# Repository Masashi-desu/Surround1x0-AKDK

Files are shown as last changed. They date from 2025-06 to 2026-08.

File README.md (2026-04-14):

# Surround1x0-AKDK

Generated by [Auto-Keyboard-Design-Kit](https://auto-kdk.pages.dev/)

## Preview

- 3D View

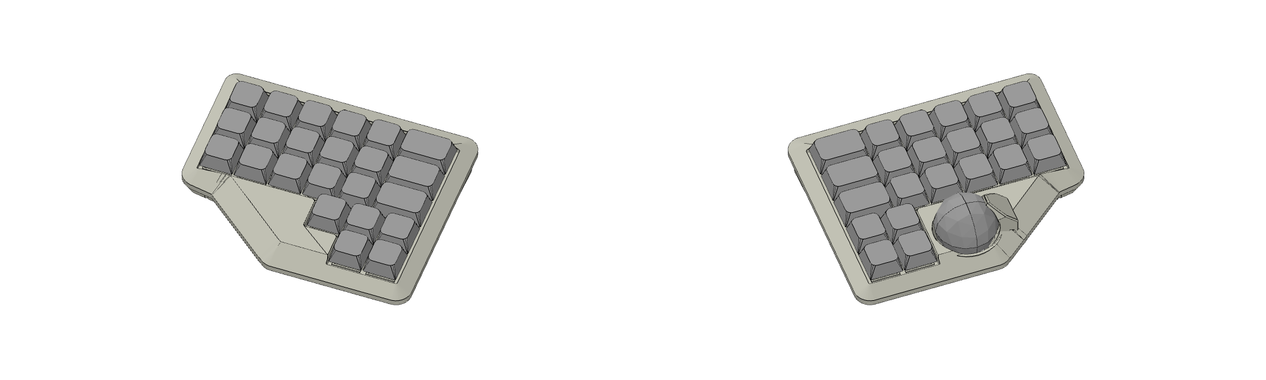
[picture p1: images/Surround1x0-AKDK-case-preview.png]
Case Preview


- Top View

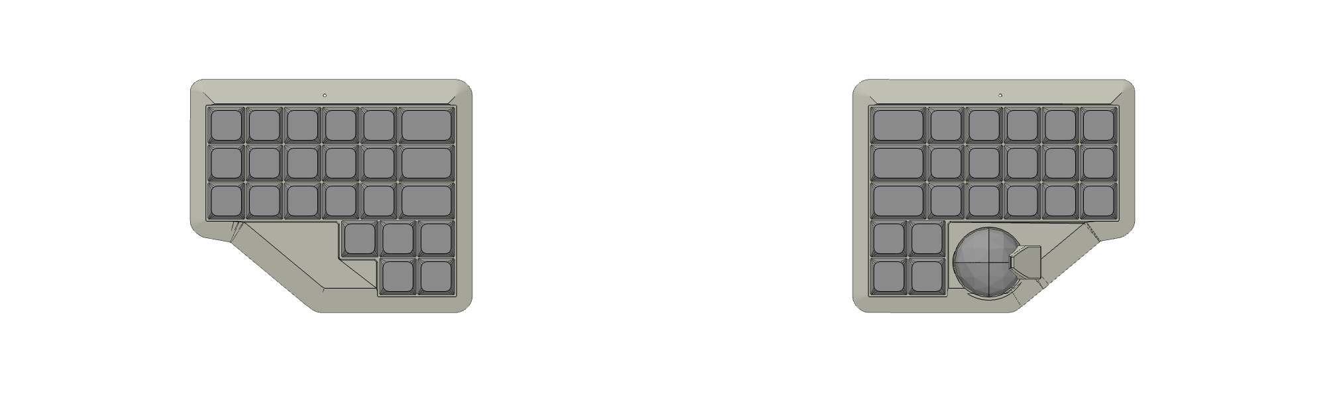
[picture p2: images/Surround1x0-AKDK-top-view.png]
Top View


## Keymap

Mac/Win と US/JIS の差分キーは、それぞれ `Mac/Win` と `US/JIS` の順で表記しています。SVG は `config/keymap.keymap` から自動生成されます。

Keymap

## Parts List

|Part|Quantity|
|---|---|
|wireless controller|2|
|Conthrough(2.5mm, 9pin)|4|
|Battery|2|
USB-C cable|1|
|Choc V2 switch and socket|45|
|Diode|45|
|Keycap|45|

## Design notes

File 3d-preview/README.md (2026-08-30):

# 3D preview model pipeline

`3d-preview` は、Blender の編集元データ、リポジトリ内の設計データから部品を再生成するスクリプト、検証用スクリプト、Web 向け GLB の書き出し処理をまとめたディレクトリです。

編集の中心は [`Surround1x0-AKDK.blend`](./Surround1x0-AKDK.blend) です。自動生成された部品を手作業で直すのではなく、原則として対応する入力データまたは `scripts/` 内の生成スクリプトを修正して再生成します。

## 全体の関係

```text
pcb/*.json ──────────────> build_pcb_from_repository.py ──> PCB
                                  │
                                  ├─> build_choc_hotswap_sockets.py
                                  ├─> build_controller_sensor_modules.py
                                  └─> setup_assembly_exploded_view.py

keycaps/ ────────────────> 利用者がカスタムできる3Dプリント用成果物

.blend 内のキーキャップ ─> build_choc_v2_switches.py ─────> Switches

生成済みの各部品 ─────────> verify_*.py / render_*.py ───────> .tmp/ の検証資料

更新済み .blend ─────────> setup_assembly_exploded_view.py ─> 分解レイヤー
        └────────────────> export_web_glb.py ───────────────> Black / White / Web GLB
```

基本の更新順は次のとおりです。

1. 変更対象に対応する生成スクリプトだけを実行する。PCB、ソケット、コントローラー／センサーをまとめて更新するときは `build_pcb_from_repository.py` を使う。
2. 対応する `verify_*.py` を実行する。
3. 個別の生成スクリプトを実行した場合や親子関係を変更した場合は、`setup_assembly_exploded_view.py` を再実行する。
4. Web用モデルを更新するときは、最後に `export_web_glb.py` で GLB を書き出す。

これは全工程を毎回実行するための固定ワークフローではありません。変更した部品に関係する処理だけを選んで使用します。

## 主要な生成・更新スクリプト

| スクリプト | 主な入力 | `.blend` への変更 | 保存と依存関係 |
| --- | --- | --- | --- |
| [`build_choc_v2_switches.py`](./scripts/build_choc_v2_switches.py) | `.blend` 内の既存スイッチ位置とキーキャップの `module_id` / `profile` | Kailh Choc V2 の各部品を再生成 | 単体では保存も分解レイヤー再構築もしない。実行後に保存し、続けて分解ビューを更新する |
| [`build_pcb_from_repository.py`](./scripts/build_pcb_from_repository.py) | `../pcb/Surround1x0-AKDK-{left,right}-pcb.json` | 左右 PCB の外形、穴、銅箔などを再生成 | ソケット生成、コントローラー／センサー生成、分解ビュー設定を内部で順番に呼び出し、最後に `.blend` を保存する |
| [`build_choc_hotswap_sockets.py`](./scripts/build_choc_hotswap_sockets.py) | PCB JSON 内の CPG135001S30 フットプリント | ホットスワップソケットを再生成 | 単独実行時も分解ビューを更新して `.blend` を保存する。PCB 一括生成からも呼ばれる |
| [`build_controller_sensor_modules.py`](./scripts/build_controller_sensor_modules.py) | PCB の配置情報、Auto-KDK とマウスセンサーの寸法・参照情報 | コントローラー、コンスルー、電池／コネクター、マウスセンサー、FPC を再生成 | 既定では分解ビューを更新して `.blend` を保存する。PCB 一括生成からも呼ばれる。`--no-save` と `--no-exploded` を指定可能 |
| [`setup_assembly_exploded_view.py`](./scripts/setup_assembly_exploded_view.py) | 現在の Blender オブジェクトとカスタムプロパティ | 部品を分解レイヤー用 Empty に再分類し、ドライバーを設定 | `.blend` を保存する。`--spacing`、`--assembled`、`--output` を指定可能 |
| [`export_web_glb.py`](./scripts/export_web_glb.py) | 更新済みの `.blend` とマテリアル | 書き出し時だけ組立状態と色を適用 | `.blend` は保存せず、3 個の GLB を出力する。キー刻印の `Legend_*` は出力対象外 |

### PCB 一括生成について

`build_pcb_from_repository.py` は PCB だけのスクリプト名ですが、内部で次も再生成します。

```text
build_pcb_from_repository.py
├── build_choc_hotswap_sockets.py
├── build_controller_sensor_modules.py
└── setup_assembly_exploded_view.py
```

したがって通常の構成同期では `npm run model:pcb` を 1 回実行すれば、PCB、ソケット、コントローラー／センサー、分解レイヤーまで更新されます。ソケットまたはコントローラーだけを調整しているときは、対応する個別コマンドを使えます。

## キーキャップ成果物とBlenderモデル

[`../keycaps`](../keycaps) は、利用者がそのまま3Dプリントしたり、用途に合わせてカスタムしたりできる配布成果物です。Blenderモデルの自動生成依存ではなく、独立した成果物としてバージョン管理します。このため、配布元や生成時のファイル名が変わっても `3d-preview` のスクリプト変更は必要ありません。

現在の [`Surround1x0-AKDK.blend`](./Surround1x0-AKDK.blend) には、今回取り込んだキーキャップ形状が格納済みです。`keycaps/` からBlenderへ再取り込みする常設スクリプトは置かず、将来モデル側も更新するときは、その時点の形状と要件に合わせて作業します。3MFは黒色キーボード向けですが、Blender上の色はマテリアルと `export_web_glb.py` のカラーバリエーションが管理します。

- ハイプロファイルのホーミングは、大西配列の T と O に相当する左右の物理位置 `switch-01-03` に割り当てる。
- ロープロファイルのホーミングは、手前側の外端、つまり左手 DEF と右手 BSP に割り当てる。
- 白黒ともキー刻印は表示しない。Blender 内の `Legend_*` も非表示にし、GLB 書き出し時にも除外する。
- 白ではハイプロファイルのホーミングバーとトラックボールにグレーを使う。
- Web ビューアー上での動的な色切り替えは [`../site/src/main.js`](../site/src/main.js)、書き出し済み Black / White GLB の色は [`export_web_glb.py`](./scripts/export_web_glb.py) が管理する。

## 検証スクリプト

検証スクリプトは `.blend` を更新せず、リポジトリ直下の `.tmp/` に JSON や SVG を生成します。

| 生成対象 | 検証スクリプト | 主な出力先 |
| --- | --- | --- |
| PCB | [`verify_pcb_holes.py`](./scripts/verify_pcb_holes.py) | `../.tmp/pcb-hole-verification/` |
| ホットスワップソケット | [`verify_choc_hotswap_sockets.py`](./scripts/verify_choc_hotswap_sockets.py) | `../.tmp/socket-model/` |
| コントローラー／センサー | [`verify_controller_sensor_modules.py`](./scripts/verify_controller_sensor_modules.py) | `../.tmp/controller-sensor-model/` |

形状生成スクリプトを変更した場合は、最低でも対応する検証スクリプトを再実行します。`build_pcb_from_repository.py` は複数部品を更新するため、PCB、ソケット、コントローラー／センサーの 3 検証を実行します。

## レンダリングとオーバーレイ

次のスクリプト群は、寸法検証を画像で確認するための補助処理です。`render_*.py` は Blender で現在モデルをレンダリングし、対応する `make_*.py` は Pillow を使って参照画像や測定値との比較画像を作ります。

| 対象 | Blender レンダリング | オーバーレイ生成 | 出力先 |
| --- | --- | --- | --- |
| コントローラー／センサー | [`render_controller_sensor_validation.py`](./scripts/render_controller_sensor_validation.py) | [`make_controller_sensor_overlays.py`](./scripts/make_controller_sensor_overlays.py) | `../.tmp/controller-sensor-model/` |
| コントローラーとケース | [`render_controller_case_alignment.py`](./scripts/render_controller_case_alignment.py) | [`make_controller_case_overlays.py`](./scripts/make_controller_case_overlays.py) | `../.tmp/controller-bottom-reference/output/` |
| マウスセンサーとケース | [`render_mouse_sensor_alignment.py`](./scripts/render_mouse_sensor_alignment.py) | [`make_mouse_sensor_alignment_overlays.py`](./scripts/make_mouse_sensor_alignment_overlays.py) | `../.tmp/mouse-sensor-alignment/` |

オーバーレイ生成は、対応するレンダリングと必要な `verify_*.py` の測定 JSON を先に作ってから実行します。`.tmp/` 以下は再生成可能な検証成果物で、編集元データではありません。

## 実行方法

### npm コマンド

Blender の主要コマンドは [`../site/package.json`](../site/package.json) に定義されています。`site` ディレクトリから実行します。

```sh
cd site

npm run model:pcb
npm run model:verify:pcb
npm run model:verify:socket
npm run model:verify:controller
npm run model:export
```

個別更新用に `npm run model:socket` と `npm run model:controller` もあります。`npm run model:sync` は `model:pcb` の後に `model:export` を実行しますが、検証は含みません。

### Blender スクリプトの直接実行

`package.json` にないスクリプトは、リポジトリ直下から次の形式で実行できます。

```sh
BLENDER=/Applications/Blender.app/Contents/MacOS/Blender

"$BLENDER" \
  --background 3d-preview/Surround1x0-AKDK.blend \
  --python-exit-code 1 \
  --python 3d-preview/scripts/verify_pcb_holes.py
```

引数を受け取るスクリプトでは、Blender の引数との境界に `--` を置きます。

```sh
"$BLENDER" \
  --background 3d-preview/Surround1x0-AKDK.blend \
  --python-exit-code 1 \
  --python 3d-preview/scripts/setup_assembly_exploded_view.py \
  -- --spacing 30
```

`build_choc_v2_switches.py` は単体では `.blend` を保存しないため、Blender の Scripting ワークスペースで実行して結果を確認し、明示的に保存してください。

## GLB の出力先

`export_web_glb.py` は、分解ビューのドライバーを一時的に組立状態へそろえ、次を出力します。

| 出力 | 用途 |
| --- | --- |
| [`Surround1x0-AKDK-Black.glb`](./Surround1x0-AKDK-Black.glb) | 黒カラーバリエーションの確認用 |
| [`Surround1x0-AKDK-White.glb`](./Surround1x0-AKDK-White.glb) | 白カラーバリエーションの確認用 |
| [`../site/public/models/surround1x0-akdk.glb`](../site/public/models/surround1x0-akdk.glb) | Web ビューアーが読み込む配信用モデル |

書き出し後は `site` で `npm run build` を実行し、Web 側のモデル読み込みと色切り替えを確認します。

## 更新時のチェックリスト

- 生成物ではなく、対応する設計データまたは生成スクリプトを修正したか。
- 変更した部品に対応する `verify_*.py` を実行したか。
- 新しいオブジェクトを追加した場合、分解レイヤーを再構築したか。
- Black / White / Web の 3 GLB を再出力したか。
- Web 側の色定義も変更した場合、`site/src/main.js` と `export_web_glb.py` の役割の違いを確認したか。

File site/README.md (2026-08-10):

# Surround1x0-AKDK Three.js Preview

ViteとThree.jsで`3d-preview/Surround1x0-AKDK.blend`のGLBを表示します。

```bash
cd site
npm install
npm run model:sync
npm run dev
```

## 機能

- Black / Warm Ivory / GLB Originalの色表示切替
- 全体、左手側、右手側、PCB基板、Auto-KDKマイコン基板、コンスルーピン、マウスセンサー、ケース、スイッチ、スイッチソケット、キーキャップ、トラックボール、コネクタ表示
- Choc V2茶軸／青軸を内部部品ではなく一式として選べる代表単体表示
- キースイッチ単体表示中の内部パーツExploded View
- ケース上下、ソケット、PCB、コンスルー、マイコン基板、マウスセンサー、スイッチ、キーキャップ、トラックボールのExploded View
- 分解量スライダー、表示対象へのカメラフィット、視点リセット

GLBはBlenderの`exploded_view_layer`と`exploded_view_order`カスタムプロパティを
保持します。スイッチ内部の部品はGLBに含まれますが、WebのExploded Viewでは
スイッチ一式として動きます。表示対象から個別のキースイッチを選択した場合だけ、
「分解」でケース・ステム・ばね・接点などの内部パーツを展開します。

## PCBからプレビューへの反映

`pcb/Surround1x0-AKDK-left-pcb.json`と
`pcb/Surround1x0-AKDK-right-pcb.json`を元に、基板外形、配線、露出パッド、
シルクと実際に貫通したドリル穴を持つベアPCBをBlenderへ再生成します。
EasyEDAの`HOLE`と多層`PAD`のドリル値は半径として読み取り、直径へ変換してBoolean加工します。
マイコン接続用フットプリントのスルーホールとパッドはPCB側に残し、Auto-KDK基板、
9ピン×2列のコンスルー、LiPoはそれぞれ独立ジオメトリとして配置します。
右手側には13.4 × 7.4 mmのPAW3222マウスセンサー基板と0.5 mmピッチ6ピンFPCも配置します。
スイッチソケットはCPG135001S30のデータシート寸法とEasyEDAの実穴位置を元に、
PCBとは別の独立パーツとして45個配置します。ダイオードは引き続きPCBモデルには
含めず、独立パーツとして追加できる構成です。

```bash
cd site
npm run model:sync
```

`model:sync`はBlenderファイルを更新してから、サイト用GLBを再出力します。

穴加工をEasyEDAの元データと照合する場合は、次を実行します。

```bash
npm run model:verify:pcb
npm run model:verify:socket
npm run model:verify:controller
```

検証結果は`.tmp/pcb-hole-verification/`へ出力され、参照穴と生成メッシュの
全体／拡大オーバーレイ、および中心・直径誤差のJSONを確認できます。
ソケットの寸法・ボス径・PCB穴中心との位置合わせは`.tmp/socket-model/`へ
オーバーレイと測定JSONを出力します。
Auto-KDK基板、コンスルーピン、マウスセンサー、FPCの寸法・配置検証は
`.tmp/controller-sensor-model/`へ測定JSON、レンダー、参照写真オーバーレイを出力します。

## GitHub Pagesへのデプロイ

`main`ブランチへのpushで`site/**`に変更が含まれる場合、
`.github/workflows/deploy-site-pages.yml`がViteをビルドしてGitHub Pagesへデプロイします。
Actionsタブから手動実行することもできます。

初回のみ、GitHubの「Settings → Pages → Build and deployment → Source」で
`GitHub Actions`を選択してください。PagesのベースパスはWorkflowからViteへ自動的に渡されます。

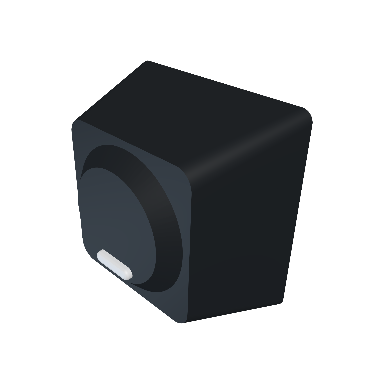
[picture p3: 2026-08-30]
keycaps/keycaps/Hiprofile-1u-Homing-519426ae.png

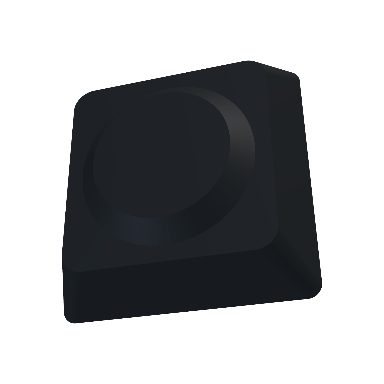
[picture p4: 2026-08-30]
keycaps/keycaps/Lowprofile-1u-93ce7806.png

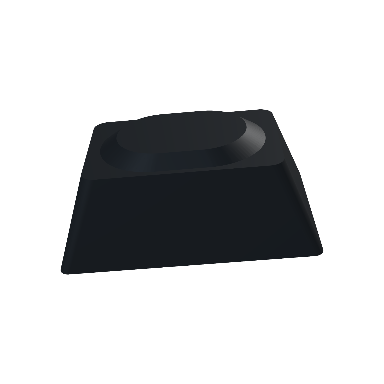
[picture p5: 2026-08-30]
keycaps/keycaps/Hiprofile-1.5u-16350801.png

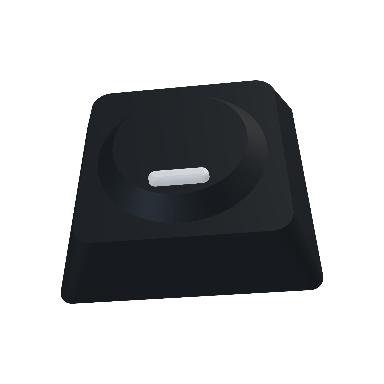
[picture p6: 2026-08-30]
keycaps/keycaps/Lowprofile-1u-Homing-1a3ae35f.png

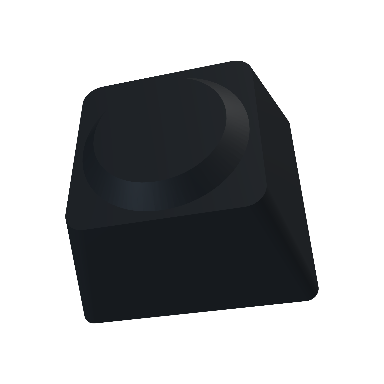
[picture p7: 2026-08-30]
keycaps/keycaps/Hiprofile-1u-170342f3.png

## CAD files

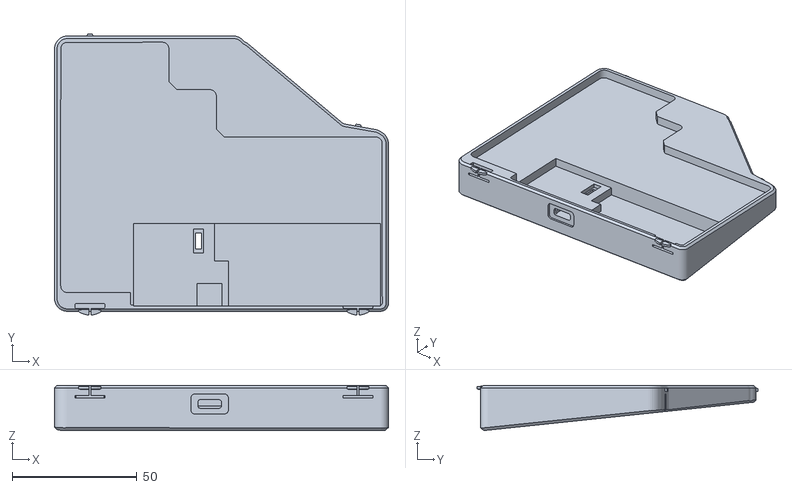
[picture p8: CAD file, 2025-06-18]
case/Surround1x0-AKDK-left-bottom-case.stl
133.9 x 112.7 x 18.1

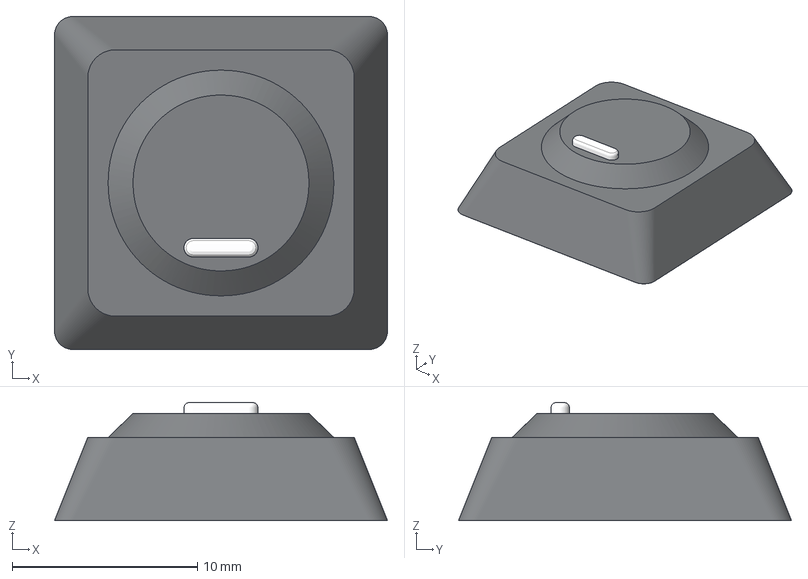
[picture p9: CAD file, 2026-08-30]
keycaps/3mf/Lowprofile-1u-Homing-1a3ae35f.3mf
18.0 x 18.0 x 6.41 mm

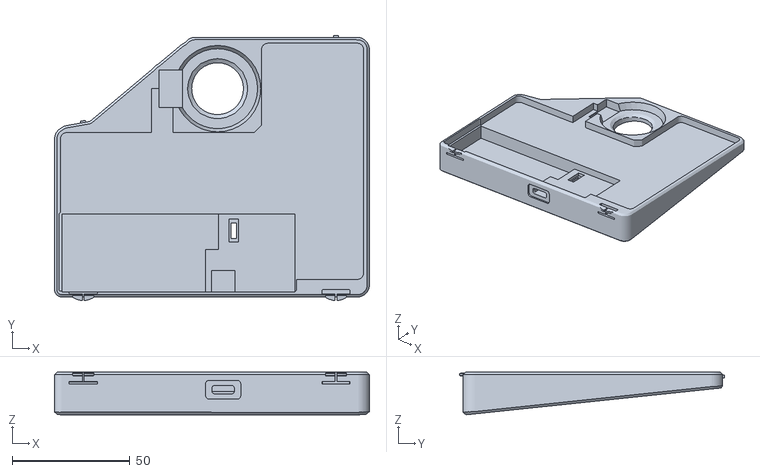
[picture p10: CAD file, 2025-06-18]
case/Surround1x0-AKDK-right-bottom-case.stl
133.9 x 112.6 x 18.1

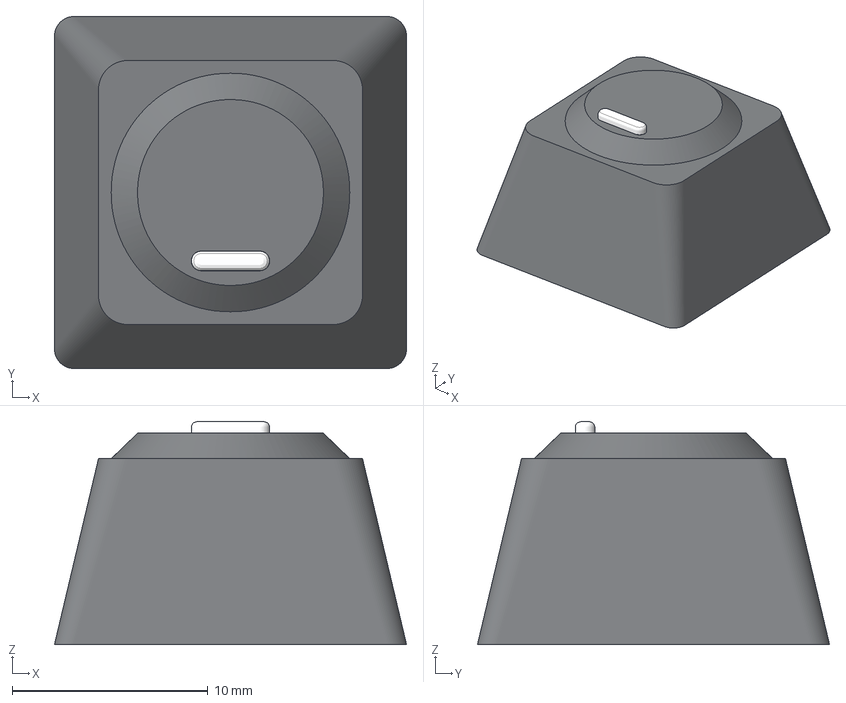
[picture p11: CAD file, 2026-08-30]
keycaps/3mf/Hiprofile-1u-Homing-519426ae.3mf
18.0 x 18.0 x 11.4 mm

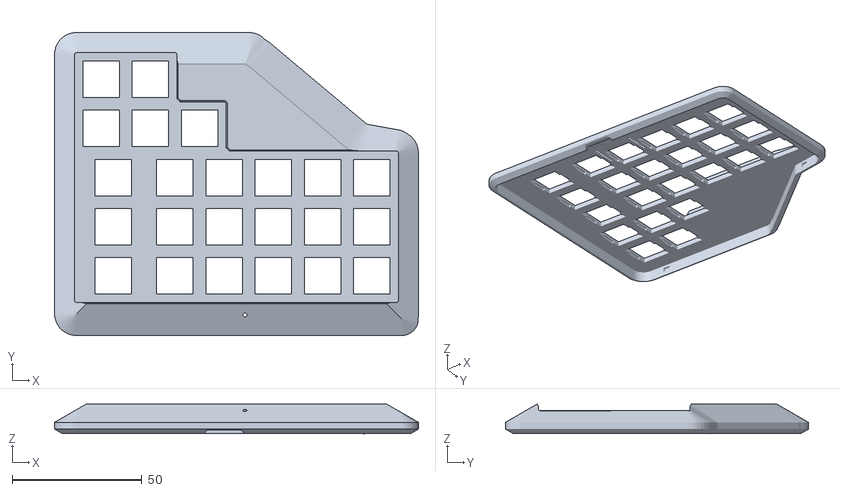
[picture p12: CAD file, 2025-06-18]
case/Surround1x0-AKDK-left-top-case.stl
140.5 x 117.0 x 11.4

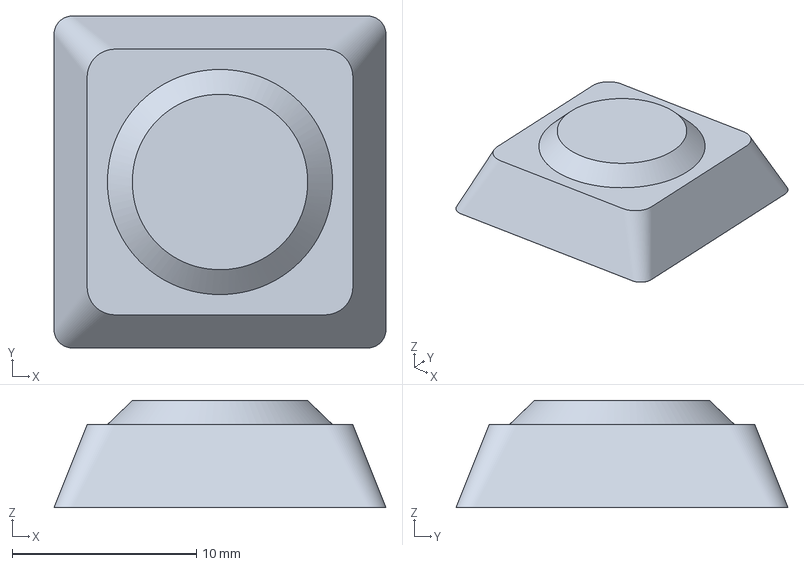
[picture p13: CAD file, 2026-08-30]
keycaps/3mf/Lowprofile-1u-93ce7806.3mf
18.0 x 18.0 x 5.81 mm

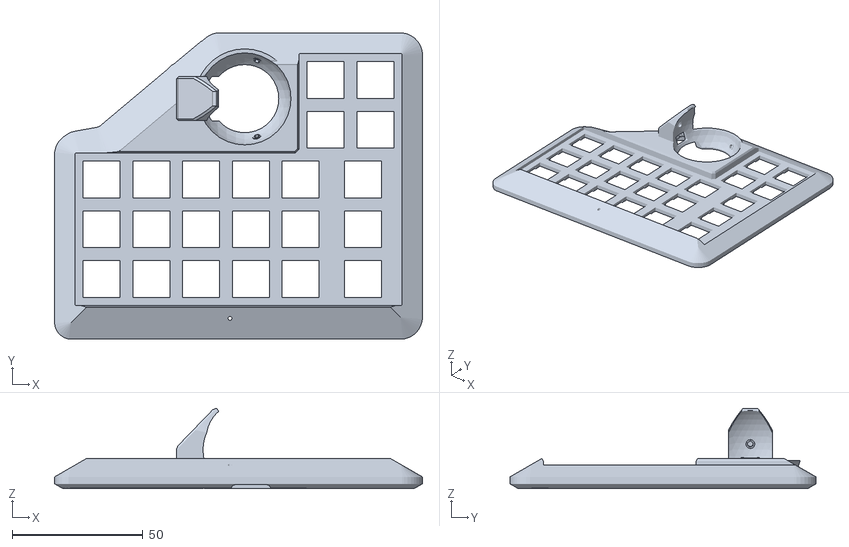
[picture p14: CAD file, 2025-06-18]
case/Surround1x0-AKDK-right-top-case.stl
140.5 x 117.0 x 30.6

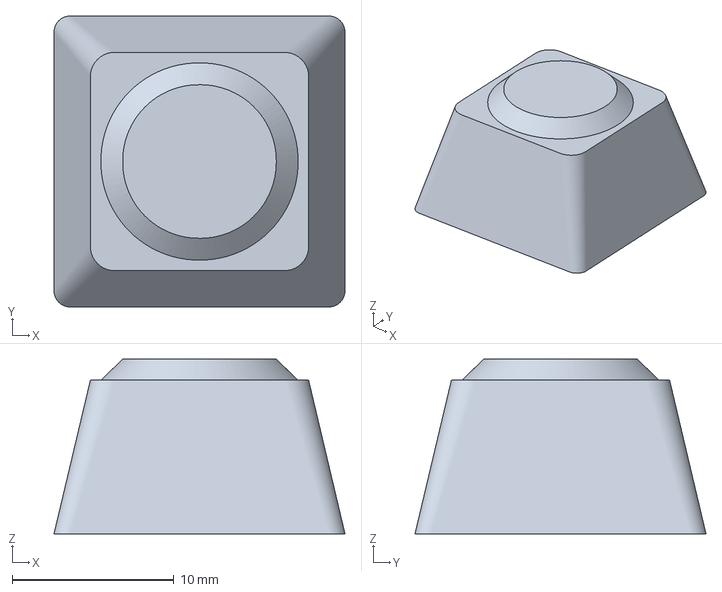
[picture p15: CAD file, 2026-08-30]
keycaps/3mf/Hiprofile-1u-170342f3.3mf
18.0 x 18.0 x 10.8 mm

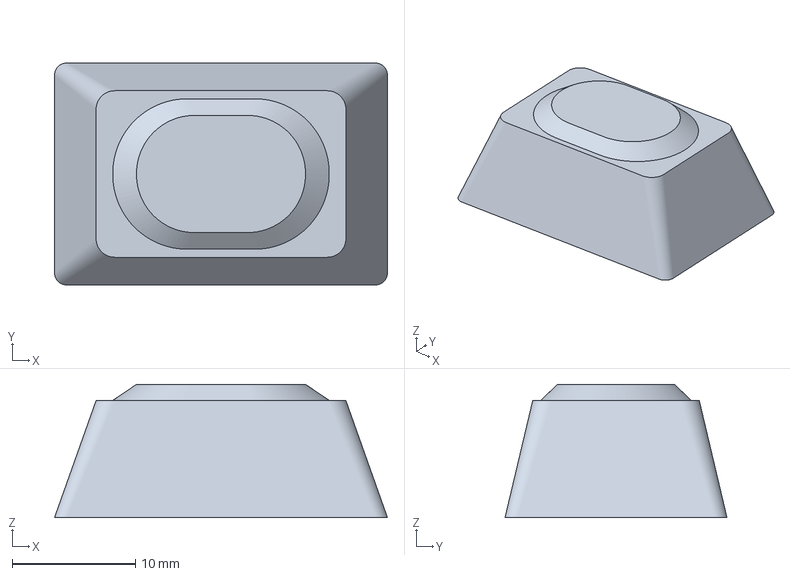
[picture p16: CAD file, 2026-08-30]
keycaps/3mf/Hiprofile-1.5u-16350801.3mf
27.0 x 18.0 x 10.8 mm

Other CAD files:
3d-preview/Surround1x0-AKDK.blend

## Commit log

2025-06-18 Update surround1x0_akdk_right.conf (#1)
    BUILD_ASSERT(DEVICE_NAME_LEN < CONFIG_BT_DEVICE_NAME_MAX);
    でエラーになる問題を修正。
2025-06-22 装飾、レイヤの改善
2025-06-28 コンボ追加。リファクタ
2025-06-28 レイヤをリセットするカスタムビヘイビアを追加
2025-06-28 binding-cells不足の問題を修正
2025-06-28 カスタムビヘイビアではなくto0を使用する方針へ変更
2025-06-28 大西配列に変更
2025-06-28 キーマップ調整
2025-06-28 コンボの発火時間を調整
2025-06-28 btレイヤ移動を変更
2025-06-29 キーマップ 微調整
2025-06-29 キーマップ微調整 MOVEレイヤから入力レイヤに戻れない問題を修正
2025-06-29 キーマップ微調整
2025-07-05 移動キー装飾キーの調整
2025-07-05 キーマップの調整
2025-07-05 移動用レイヤの改善
2025-07-06 プレビュー追加
2025-07-13 操作関連のキーマップを調整
2025-07-27 レイヤ移動とキーマップの改善
2025-07-27 キーマップ改善 Fnレイヤ移動
2025-07-30 数値、記号のレイヤの左側を移動レイヤと同じキーマップに変更
2025-07-30 レイヤの設定ミスを修正
2025-08-09 キーマップの改善
2025-08-11 トラックボールスクロール用のレイヤーを追加
2025-08-11 トラックボールスクロール対応
    トラックボールによるスクロールに対応する設定を追加
2025-08-11 自動スリープ機能の追加
    10分で自動スリープになるように設定を追加。
2025-08-11 デバッグ用のdump-configを追加
    “Dump final .config (right shield)” が走って、build-right/zephyr/.config を Artifacts: config-right としてダウンロードできるようになります。
2025-08-11 dump-config ジョブのコンテナを変更
2025-08-11 コンパイルせず.config を生成
2025-08-11 zephyr/.config ターゲットだけをビルドして .configを生成
2025-08-11 Revert "自動スリープ機能の追加"
    This reverts commit eed534183a3a0270cfe6c621140d1b21c4935140.
2025-08-11 スリープモード関係の変更を取り消し
2025-08-11 スリープモードの追加
    10分でスリープ状態に移行し、Centralのキーを押すことで復帰します。
    peripheralやトラックボールからのwakeは一旦対象外とします。
2025-08-11 トラックボールのスクロールを反転
    トラックボールのスクロールを変更することでスワイプのように操作できるように変更。
2025-08-11 ビルド時に短縮ハッシュをファイル名に付与
2025-08-11 409 Conflict 修正
    同名アーティファクトを上書き
2025-08-11 アーティファクト名に短縮ハッシュを付与
2025-08-11 ワークフローを簡略化
2025-08-11 一旦アーティファクトのリネームは保留
2025-08-11 スクロール反転
2025-08-11 修正 missing data after phandle
2025-08-11 scroller の input-processors を X反転 と Y反転 を 別々の zip_scroll_transform として連続適用する形に変更
2025-08-11 左右の反転を削除
2025-08-12 キーマップ改善 各レイヤー間の一貫性を改善
2025-08-12 defaultレイヤーのJのholdとtapが入れ替わっていた問題を修正
2025-08-12 functionレイヤーに移動するコンボが消えていた問題を修正
2025-08-17 スクロールレイヤーに左手で遷移できるように変更。使用しないコンボを削除。親指シフトに統一。
2025-08-17 スリープモードへの時間を45分に変更
2025-08-23 feat(trackball): Macナチュラルスクロール対応のスクロール反転とカーソル補正を整理 (#3)
    * Apple系 natural scroll対応
    トラックパッド併用時に自然な使用感となるようにスクロールの向きを変更。
    * surround1x0_akdk_right.overlay のパースエラー解消
    •scroller_win のコメントブロック内にあった 入れ子コメント を排除
    •ついでに process-nextt; のタイポを process-next; に修正
    * trackball_listener 直下を 反転なし に変更
    * マウスカーソルの動きが反転してしまう問題を修正
    * マウスカーソル上下反転している問題を修正
2025-08-26 feat レイヤーシフトによりwindowsでの使用に対応 (#16)
    * feat: Mac/Winレイアウトシフト用ビヘイビアを追加 (#8)
    * feat: add mac/windows layout shift toggle (#9)
    * feat: rotate modifiers through win key
    * fix: include layout shift behavior in keymap
    * OS切り替えボタンの位置を押せる位置に修正
    * レイアウトシフトの必要がない場合は従来のbehaviorを使用
    * LRARROWの平仄を統一
    * レイヤーシフト版モーメンタリーレイヤー&molsを追加 (#10)
    * molsを追加しレイアウト定義によるレイヤーマッピングに対応
    * feat(trackball): Mac/Win用のスクロールレイヤーとリスナー処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
2025-08-26 キーマップの調整
    数字レイヤ、記号レイヤの右手でも装飾キーを使用できるように変更。
    インデントの調整。
2025-08-31 Feature US to JIS (#20)
    * US/JIS環境切替用ビヘイビアの追加
    * 環境切り替えを設定レイヤに追加
    * 数値・記号キーをレイアウト環境対応に変更
2026-04-17 build: pin zmk v0.3.0
2026-07-12 feat: add web-ready keyboard 3d previews
    [Surround1x0-AKDK.blend]
2026-08-10 feat: add interactive 3D model preview
    [Surround1x0-AKDK.blend]
2026-08-30 feat: add customizable keycaps and refresh 3d preview
    [Hiprofile-1.5u-16350801.3mf, Hiprofile-1u-170342f3.3mf, Hiprofile-1u-Homing-519426ae.3mf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]
2026-08-30 fix: refine controller PCB and USB-C model
    [Surround1x0-AKDK.blend]
2026-09-03 fix: align 3D preview colorways
    [Surround1x0-AKDK.blend]
